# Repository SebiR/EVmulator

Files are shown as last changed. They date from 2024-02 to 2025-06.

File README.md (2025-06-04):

> [!CAUTION]
> This project includes dangerous voltages of 230V/400V, a bit of tinkering and (public) charging infrastructure.
> Build and use this project only if you know what you are doing. I am not liable for injuries or damages!

# EVmulator
A small PCB to go into IEC 62196 Typ 2 EV charging plugs to emulate a car to use a charging station as a normal outlet.

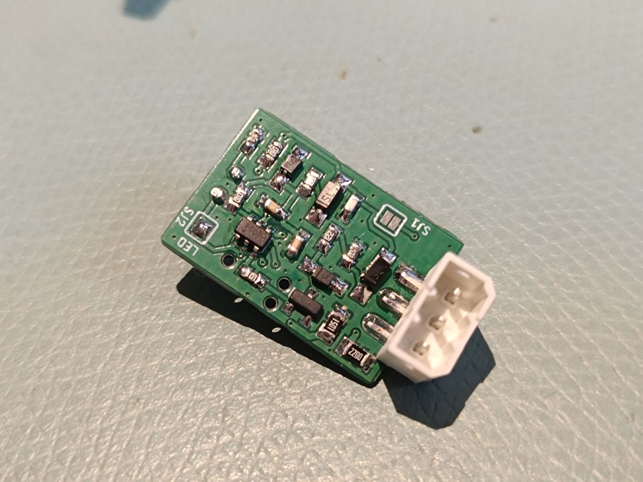
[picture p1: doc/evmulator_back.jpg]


It's currently running with an ATTiny85, although an ATTiny25 will suffice. In the future it might be done with an ATTiny10.

## Features
* Two LEDs as status indicator
* Automatic switch from connected to charging
* 13 or 32A selectable current
* EVSE Pilot monitoring
* Completely powered by the pilot signal

## Function

The EVmulator simulates a connected car for the EVSE (electric vehicle supply equipment, the wallbox)

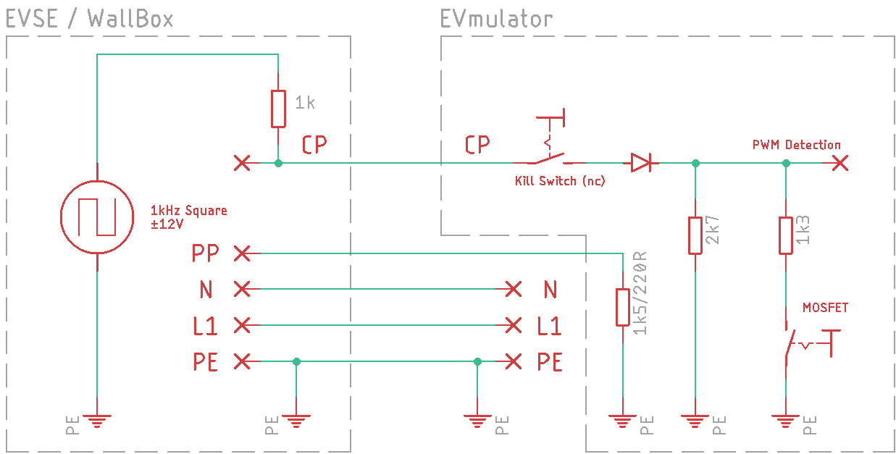
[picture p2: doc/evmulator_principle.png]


The EVSE outputs a 1kHz square wave signal with ±12V referenced to PE with 1000 ohms impedance on the CP (Control Pilot) pin and measures the voltage of the CP line.
As the EVmulator has a 1300 ohms resitor to PE, the positive voltage of the CP line is pulled to 9V and the EVSE detects a connected car.

After connecting, the EVmulator will detect the 1kHz PWM signal on the CP line and after approx. 5 seconds of PWM, the second restitor with 4.7kohms will be connected in parallel to the first resitor. As the voltage on the CP line drops to 6V, the EVSE will recognize the emulator as a charging car.

More information on Type 2 Signaling can be found here (in German):
https://www.goingelectric.de/wiki/Typ2-Signalisierung-und-Steckercodierung/

To end the charging process, a magnet is placed on the plug, opening a reed switch and signaling the end of charge to the charger.

## Usage

### Connection
Connect the three terminals of the EVmulator with the according pins of your IEC 62196 Type 2 male plug:

| Pin  | Function | Description |
|---|---|---|
| PP  | Control Pilot | maximum current of the cable defined by a resistor |
| PE  | Earth | Commond ground for communication |
| CP  | Control Pilot | Communication line between car and charger |

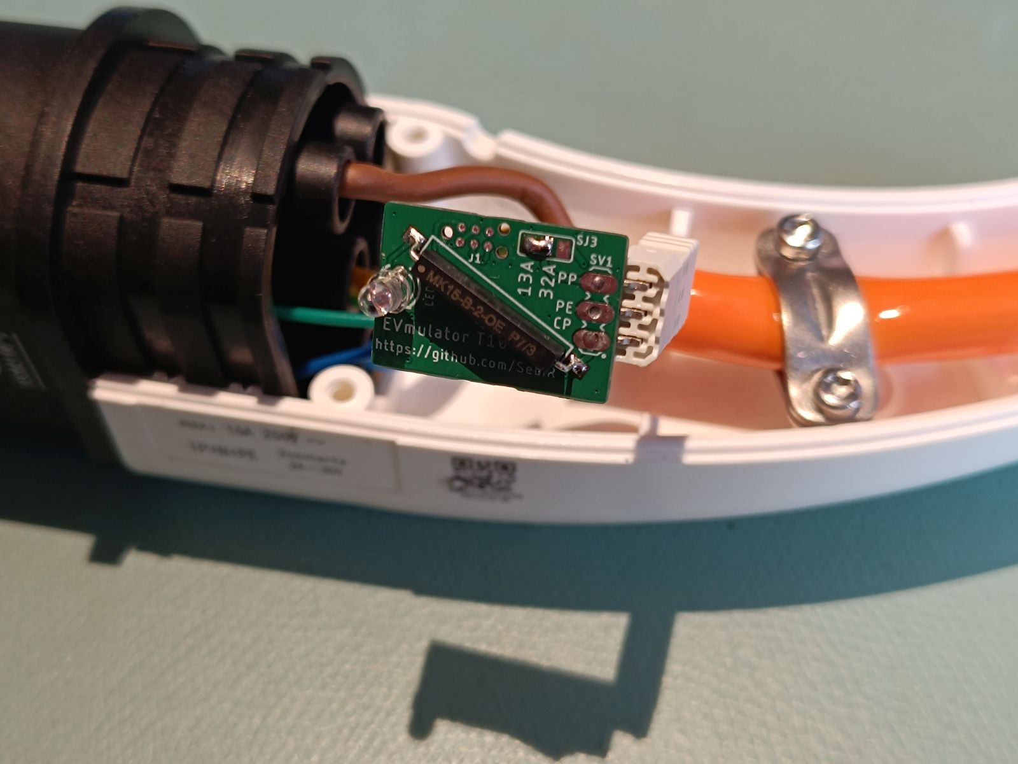
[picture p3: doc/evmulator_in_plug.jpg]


### Solder Jumpers

There are two SMT solder jumpers located on the component side of the PCB:<br>
**SJ1** bypasses the internal reed switch in case you want to use a key switch or a push button to stop the charging process. Use NC (normally closed "openener" switches).<br>
**SJ2 LED** has to be closed after flashing the microcontroller to activate the status LED. The TPI programming interface is a bit finicky when it comes to other components on the programming lines.<br>

And there's one solder jumper on the side with the reed switch:<br>
**SJ3 13/32A** let's you select between a max. current of 13A or 32A depending on your application. Always make sure to use rated cables and connectors!

### Inside the plug

Drill a 3mm hole in the plug and put the LED through it. Fix the board with a bit of silicone or hot glue and you're done!

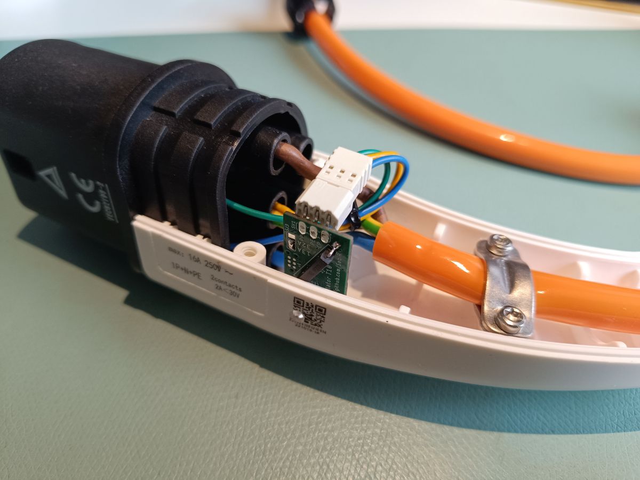
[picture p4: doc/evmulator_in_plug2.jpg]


If you want, you can add a label:

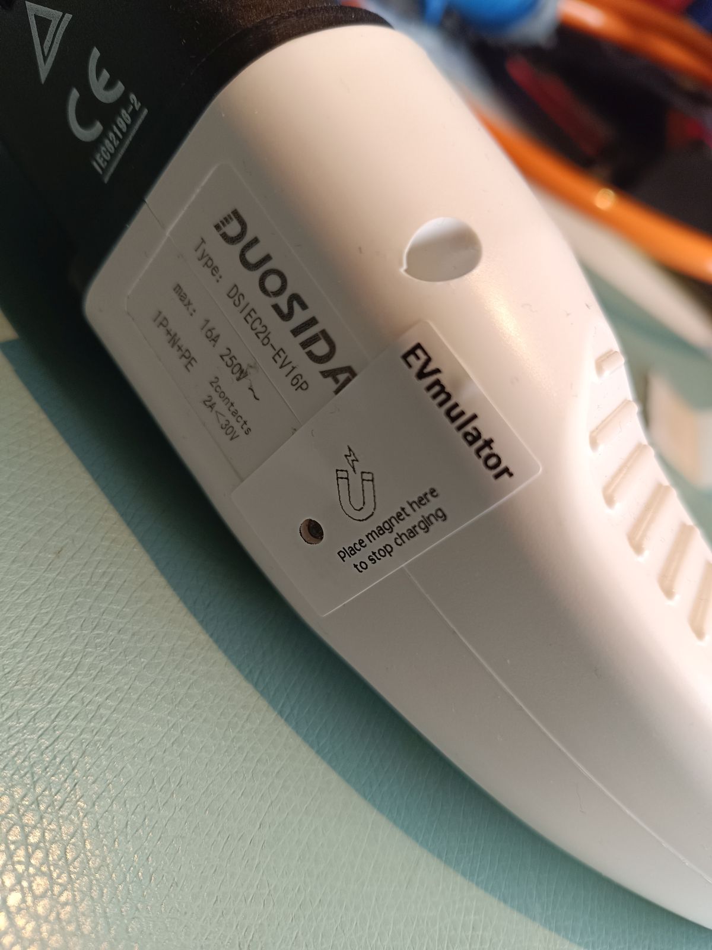
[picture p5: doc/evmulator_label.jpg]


### In the field
Just connect you Type 2 plug to the wallbox or charging station and authorize the charging process as you would normally.
The EVmulator will signal the charger that a car has been connected and that it is charging.<br>

To stop the charging process, place a magnet over the reed switch and unplug the plug.

| LED Behavior | State |
|---|---|
| Quick blink (1 ms flash every ~32 ms) | Idling, waiting for CP signal |
| Slow blink (1 ms flash every ~125 ms) | Checking if the CP signal is valid |
| Very slow blink (1 ms flash every ~1 s) | Charging |

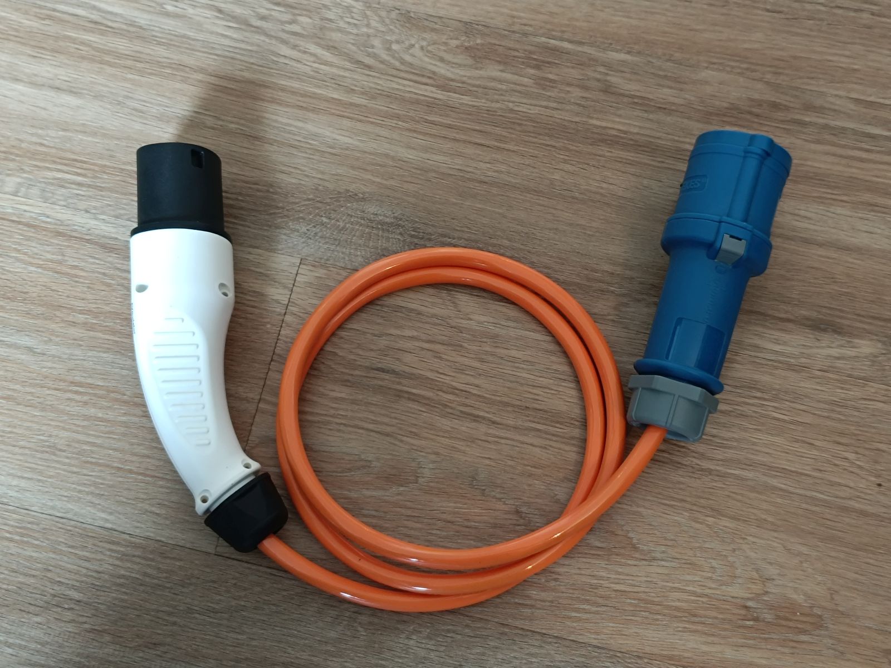
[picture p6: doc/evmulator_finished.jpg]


## Firmware

The firmware is written for the ATTiny10 microcontroller using the Arduino IDE and the <a href="https://github.com/technoblogy/attiny10core">attiny10core</a> board definitions.

### Hardware Configuration

| Pin  | Function | Description |
|---|---|---|
| PB0  | LED Output | Blinks to indicate system state |
| PB1  | CHARGE_ON (Output) | Controls a MOSFET for to signal Charging state |
| PB2  | Frequency Input | Connected to external ~1kHz square wave, also Timer0 clock source |

### System Clock and Power Settings

- The system clock is derived from the 128 kHz Watchdog oscillator.
- A clock prescaler divides this to 32 kHz system frequency.
- The ADC and analog comparator are disabled to save power.
- The microcontroller primarily stays in `SLEEP_MODE_IDLE`, waking periodically via the Watchdog Timer interrupt.

### State Machine

The firmware operates in three states:

1. **IDLE**  
   - Wakes every ~32 ms via WDT.
   - If no external clock signal is detected (TCNT0 == 0), stays in IDLE.
   - If a clock signal is consistently present for 10 cycles, transitions to MEASURE.

2. **MEASURE**  
   - Wakes every ~125 ms.
   - Measures frequency using Timer0 (externally clocked).
   - If the frequency is above 500 Hz for 10 cycles, transitions to CHARGE.
   - Remains in MEASURE as long as signal is present and below 500 Hz.

3. **CHARGE**  
   - Wakes approximately every second.
   - Enables the CHARGE_ON MOSFET (PB1 high).
   - If frequency drops below 500 Hz for 5 consecutive cycles, reverts to MEASURE.

### LED Signal Behavior

The LED (on PB0) provides visual feedback for debugging and operational awareness:

| LED Behavior | State(s) | Meaning |
|---|---|---|
| Quick blink (1 ms flash every ~32 ms) | IDLE | Signal inactive or low frequency detected |
| Slow blink (1 ms flash every ~125 ms) | MEASURE | Signal detected, measuring frequency |
| Very slow blink (1 ms flash every ~1 s) | CHARGE | Charging enabled, monitoring signal |

All blinking is implemented by flashing the LED for 1 ms during each WDT interrupt.

### Power Optimization

- All unnecessary peripherals (ADC, comparator) are disabled.
- WDT interval is adjusted dynamically based on state.
- Sleep modes and minimal active time are used to reduce power consumption.
- Timer0 uses an asynchronous external clock, allowing operation even in low-power modes.

## Other

During development, I also created the <a href="https://github.com/SebiR/EVSE_Emulator_Shield">EVSE Emulator Shield</a> to test the EVmulator

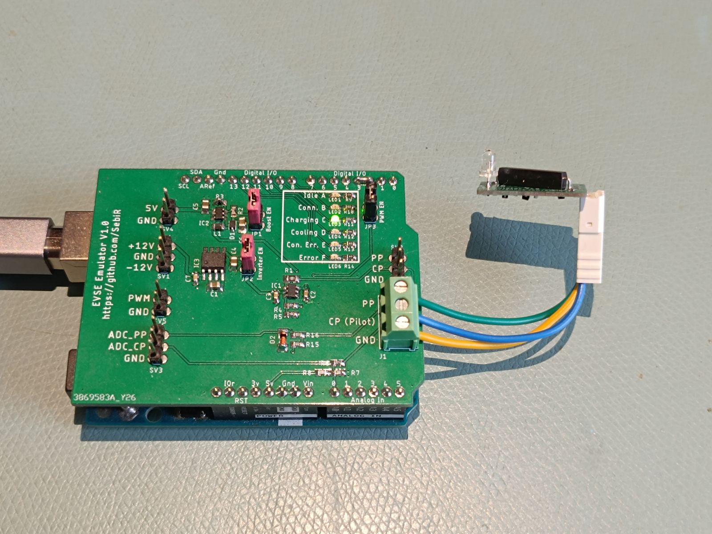
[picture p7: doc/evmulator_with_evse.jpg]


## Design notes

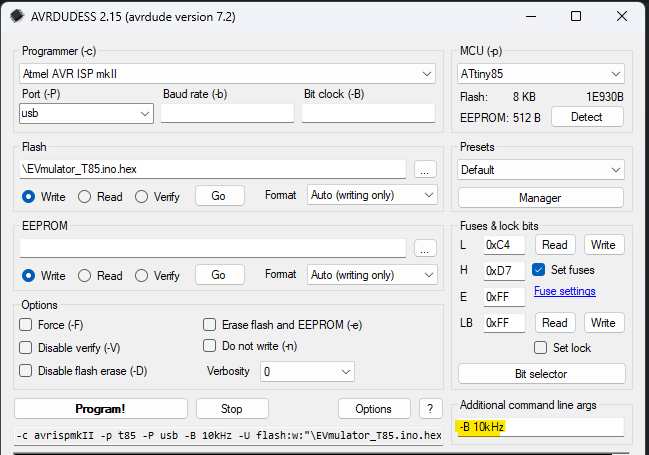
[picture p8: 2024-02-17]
doc/avr_dudess_settings.png

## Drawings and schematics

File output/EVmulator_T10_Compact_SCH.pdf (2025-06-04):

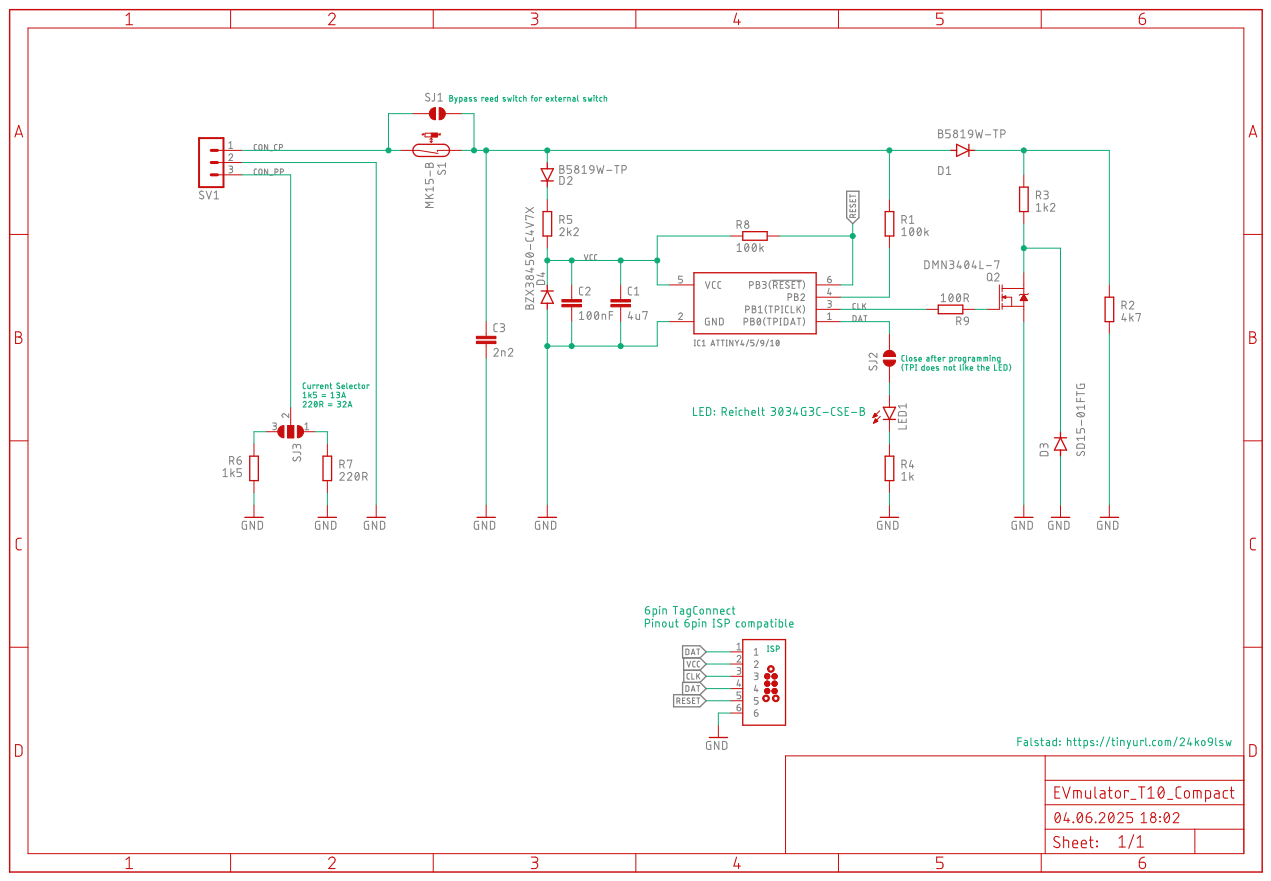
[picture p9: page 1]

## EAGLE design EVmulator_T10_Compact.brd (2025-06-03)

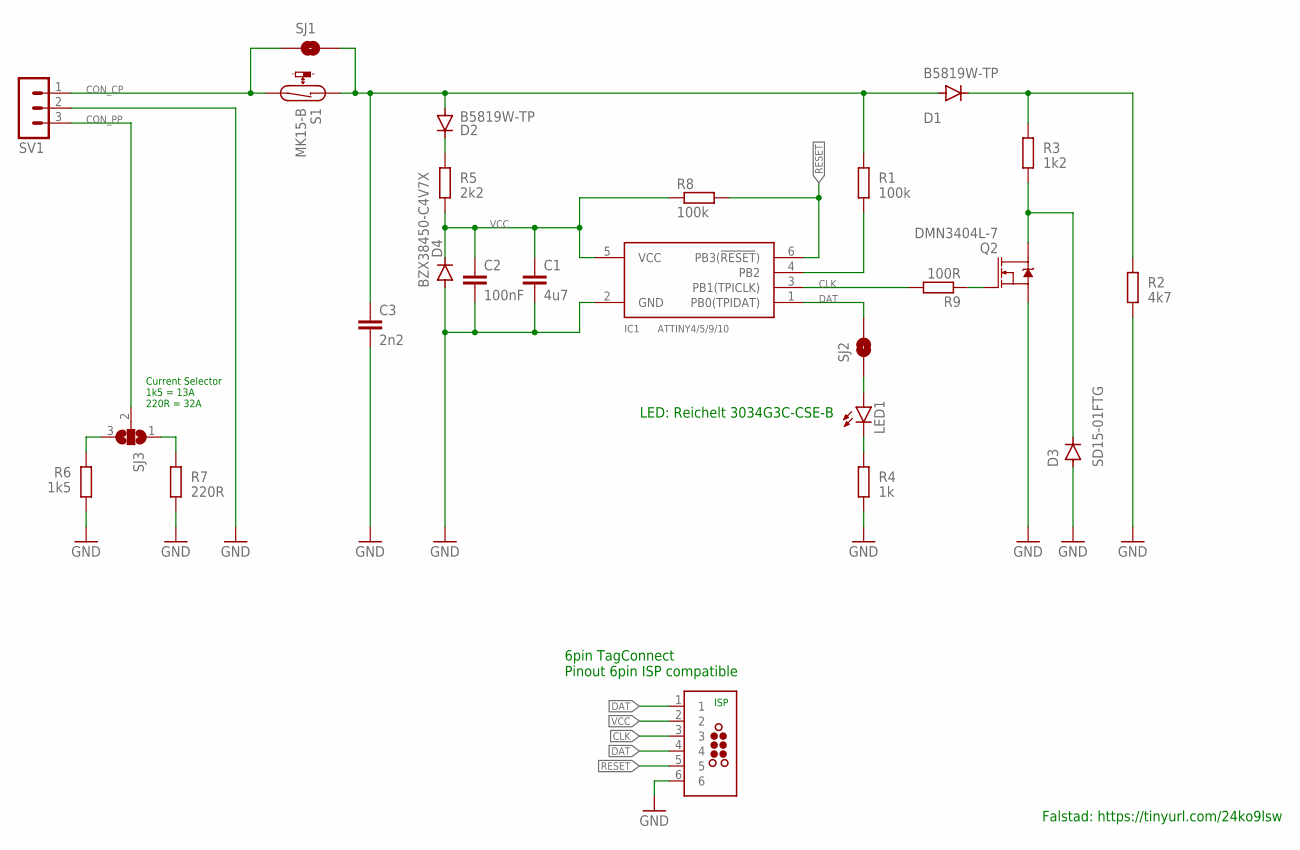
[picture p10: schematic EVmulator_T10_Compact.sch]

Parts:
C1: 4u7; C0603
C2: 100nF; C0603
C3: 2n2; C0603
D1, D2: B5819W-TP; SOD123
D3: SD15-01FTG; SOD323-W
D4: BZX38450-C4V7X; SOD323-W
IC1: ATTINY4/5/9/10; SOT23-6
J1: TAG-CONNECT_TC2030-MCP-NL
LED1: LED3MM
Q2: DMN3404L-7; SOT23-3
R1, R8: 100k; R0603
R2: 4k7; R0603
R3: 1k2; R0603
R4: 1k; R0603
R5: 2k2; R0603
R6: 1k5; R0805
R7: 220R; R0805
R9: 100R; R0603
S1: MK15-B; MK15
SJ1, SJ2: JUMPER-SMT_2_NO_SILK; SMT-JUMPER_2_NO_SILK
SJ3: SJ2W; SJ_2
SV1: MA03-1

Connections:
CLK: IC1.3 (PB1(TPICLK)), J1.3, R9.2
CON_CP: S1.2, SJ1.1, SV1.1
CON_PP: SJ3.2, SV1.3
CP: C3.1, D1.A, D2.A, R1.1, S1.1, SJ1.2
DAT: IC1.1 (PB0(TPIDAT)), J1.1, J1.4, SJ2.2
GND: C1.2, C2.2, C3.2, D3.A, D4.A, IC1.2 (GND), J1.6, Q2.2 (S), R2.1, R4.1, R6.1, R7.1, SV1.2
unnamed: Q2.1 (G), R9.1
unnamed: IC1.4 (PB2), R1.2
unnamed: D3.C, Q2.3 (D), R3.1
unnamed: LED1.K (C), R4.2
unnamed: D1.C, R2.2, R3.2
unnamed: D2.C, R5.2
unnamed: LED1.A, SJ2.1
unnamed: R6.2, SJ3.3
unnamed: R7.2, SJ3.1
RESET: IC1.6 (PB3(!RESET!)), J1.5, R8.2
VCC: C1.1, C2.1, D4.C, IC1.5 (VCC), J1.2, R5.1, R8.1

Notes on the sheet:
Falstad: https://tinyurl.com/24ko9lsw
Current Selector 1k5 = 13A 220R = 32A
ISP
6pin TagConnect Pinout 6pin ISP compatible
LED: Reichelt 3034G3C-CSE-B

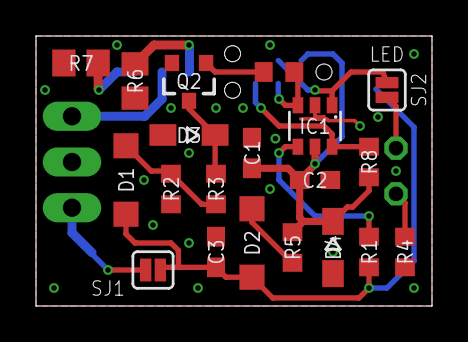
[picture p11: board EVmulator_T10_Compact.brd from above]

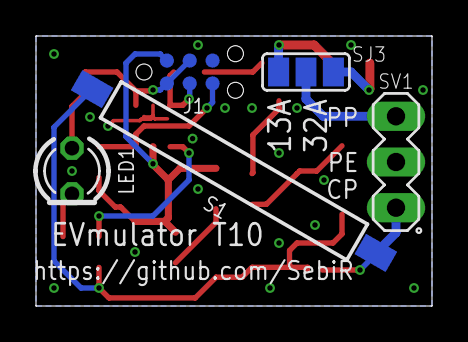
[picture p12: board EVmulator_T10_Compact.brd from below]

Board: 2 copper layers, 22.0 x 15.0 mm, 25 parts (5 on the bottom side), 17 nets.

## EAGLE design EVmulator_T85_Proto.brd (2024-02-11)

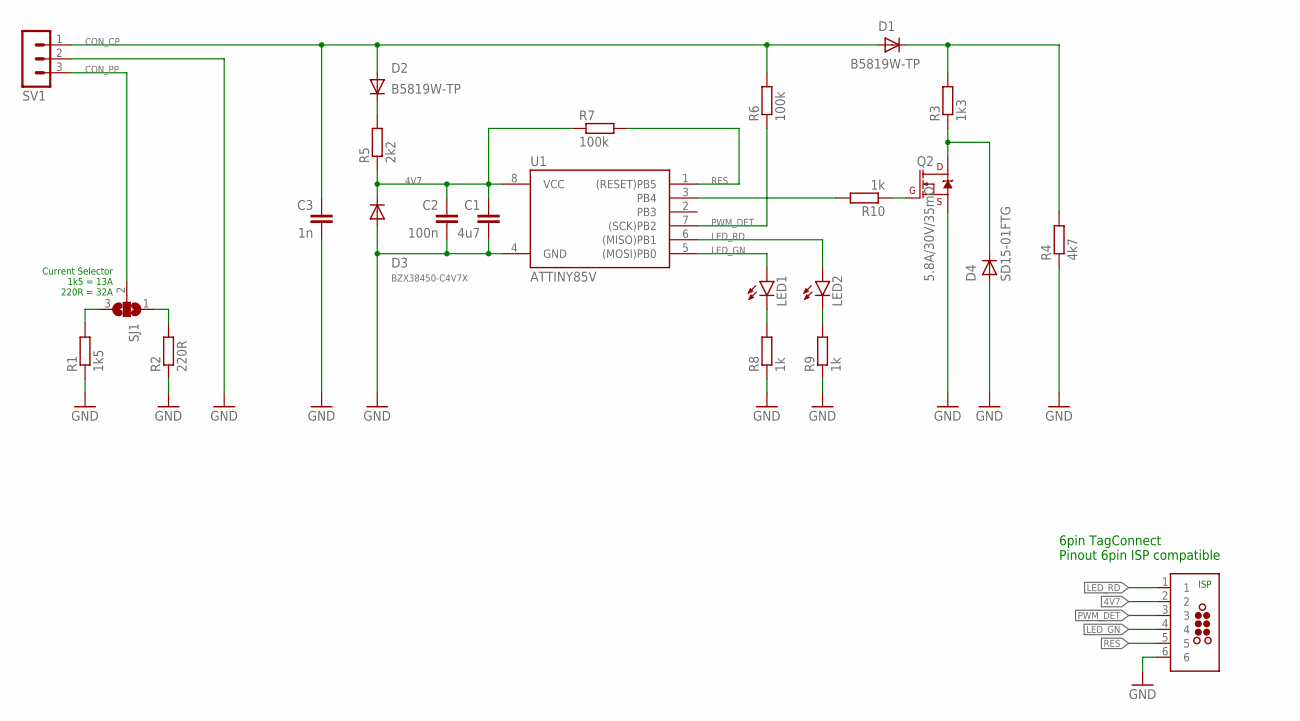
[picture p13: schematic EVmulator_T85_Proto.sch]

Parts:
C1: 4u7; C0603
C2: 100n; C0603
C3: 1n; C0603
D1, D2: B5819W-TP; SOD-123
D3: BZX38450-C4V7X; SOD-323F
D4: SD15-01FTG; SOD-323F
J1: TAG-CONNECT_TC2030-MCP-NL
LED1, LED2: LEDCHIP-LED0603; CHIP-LED0603
Q2: 5.8A/30V/35mΩ; SOT23-3
R1: 1k5; R0805
R2: 220R; R0805
R3: 1k3; R0603
R4: 4k7; R0603
R5: 2k2; R0603
R6, R7: 100k; R0603
R8, R9, R10: 1k; R0603
SJ1: SJ2W; SJ_2
SV1: MA03-1
U1: ATTINY85V; SOIC8_200

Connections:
4V7: C1.1, C2.1, D3.C, J1.2, R5.1, R7.1, U1.8 (VCC)
CON_CP: C3.1, D1.A, D2.A, R6.2, SV1.1
CON_PP: SJ1.2, SV1.3
GND: C1.2, C2.2, C3.2, D3.A, D4.A, J1.6, Q2.2 (S), R1.1, R2.1, R4.1, R8.1, R9.1, SV1.2, U1.4 (GND)
LED_GN: J1.4, LED1.A, U1.5 ((MOSI)PB0)
LED_RD: J1.1, LED2.A, U1.6 ((MISO)PB1)
unnamed: R1.2, SJ1.3
unnamed: R2.2, SJ1.1
unnamed: LED1.C, R8.2
unnamed: LED2.C, R9.2
unnamed: D4.C, Q2.3 (D), R3.1
unnamed: D1.C, R3.2, R4.2
unnamed: D2.C, R5.2
unnamed: Q2.1 (G), R10.1
unnamed: R10.2, U1.3 (PB4)
PWM_DET: J1.3, R6.1, U1.7 ((SCK)PB2)
RES: J1.5, R7.2, U1.1 ((RESET)PB5)

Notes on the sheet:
Current Selector 1k5 = 13A 220R = 32A
ISP
6pin TagConnect Pinout 6pin ISP compatible

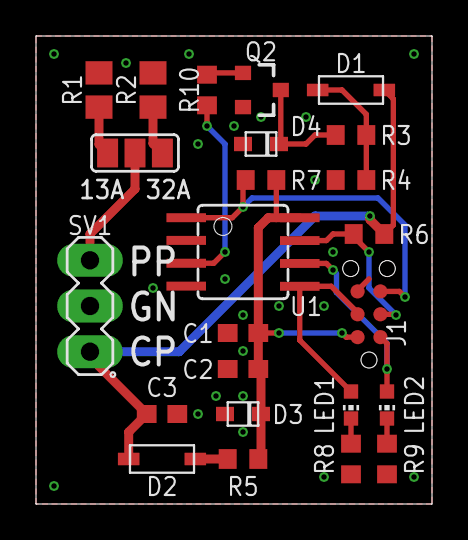
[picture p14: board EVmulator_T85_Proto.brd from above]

Board: 2 copper layers, 22.0 x 26.0 mm, 24 parts (0 on the bottom side), 17 nets.

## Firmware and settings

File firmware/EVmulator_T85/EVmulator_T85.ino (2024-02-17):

/*

Fuses:
L 0xC4
H 0xD7
E 0xFF
WD. Osc. 128 kHz
*/

#include <avr/sleep.h>
#include <avr/power.h>
#include <avr/wdt.h>
#include <avr/io.h>
#include <util/delay.h>

#define LED_GN 0  // PB0 - Green indicator LED
#define LED_RD 1  // PB1 - Red indicator LED
#define CHARGE 4  // PB4 - MOSFET to activate second resistor

#define LED_ON_TIME 5 // in ms

int pwm_good_cntr = 0;
int pwm_bad_cntr = 0;
uint8_t pwm_status = 0;

// Blank WDT interrupt
ISR(WDT_vect) {
}

// Enter Sleep Mode
void enterSleep(void) {
  //  Unfortunately, power down stops the timers, so we can't use it
  //set_sleep_mode(SLEEP_MODE_PWR_DOWN);
  set_sleep_mode(SLEEP_MODE_IDLE);
  sleep_enable();
  sleep_mode();  // Start sleep mode

  // Nothing happens until WDT timeout

  sleep_disable();
  power_all_enable();
}

// Setup the Watch Dog Timer (WDT)
// http://modelleisenbahn-steuern.de/controller/atmega8/6-5-wdtcr-register-atmega8.htm
// https://www.best-microcontroller-projects.com/attiny-ultra-low-power.html
void setupWDT() {

  MCUSR &= ~(1 << WDRF);  // Clear the WDRF (Reset Flag).

  // Setting WDCE allows updates for 4 clock cycles end is needed to
  // change WDE or the watchdog pre-scalers.
  WDTCR |= (1 << WDCE) | (1 << WDE);

  // WD triggers every ~74ms
  WDTCR = (0 << WDP3) | (0 << WDP2) | (1 << WDP1) | (0 << WDP0);

  WDTCR |= _BV(WDIE);  // Enable the WDT interrupt.
}

//  Timer 0 is used as a counter to check the presence of the pilot PWM signal
void setupT0() {

  // Normal port operation, OC0A/OC0B disconnected, Normal Timer operation
  TCCR0A = (0 << COM0A1) | (0 << COM0A0) | (0 << COM0B1) | (0 << COM0B0) | (0 << WGM01) | (0 << WGM02);

  // Ext. T0 as input. Rising edge
  TCCR0B = 0;
  TCCR0B = (0 << FOC0A) | (0 << FOC0B) | (0 << WGM02) | (1 << CS02) | (1 << CS01) | (1 << CS00);
}


void setup() {

  pinMode(LED_GN, OUTPUT);
  pinMode(LED_RD, OUTPUT);
  pinMode(CHARGE, OUTPUT);

  // Unused pins as pulled up inputs
  pinMode(2, INPUT_PULLUP);
  pinMode(3, INPUT_PULLUP);

  digitalWrite(CHARGE, LOW);
  digitalWrite(LED_GN, LOW);
  digitalWrite(LED_RD, LOW);

  ADCSRA &= ~(1 << ADEN);  // Disable ADC

  setupT0();
  setupWDT();
}

void loop() {

  // Each 74ms -> 1kHz means 74 counts
  // 30 = 900Hz, 40 =1.2kHz
  if ((TCNT0 >= 60) && (TCNT0 <= 90)) {
    pwm_bad_cntr = 0;
    pwm_good_cntr++;
  } else {
    pwm_good_cntr = 0;
    pwm_bad_cntr++;
  }
  TCNT0 = 0;

  //  approx 5 seconds of good pwm and low flag
  //  74ms period time means ~15Hz
  if (pwm_good_cntr > 5 * 15 && pwm_status == 0) {
    pwm_status = 1;
    pwm_good_cntr = 0;
  } else if (pwm_bad_cntr > 5 * 15 && pwm_status == 1) {
    pwm_status = 0;
    pwm_bad_cntr = 0;
  }

  //  Pilot PWM signal is good, switch on charging indication resistor
  if (pwm_status == 1) {
    digitalWrite(LED_GN, HIGH);
    _delay_ms(LED_ON_TIME);
    digitalWrite(LED_GN, LOW);

    // Tell the EVSE we're changing from connected to charging
    digitalWrite(CHARGE, HIGH);

    // Pilot PWM signal lost, switch off charging resistor
  } else {
    digitalWrite(LED_RD, HIGH);
    _delay_ms(LED_ON_TIME);
    digitalWrite(LED_RD, LOW);

    // Signal the EVSE we're not charging but in connected mode
    digitalWrite(CHARGE, LOW);
  }

  //  Everything done, go to sleep
  enterSleep();
}

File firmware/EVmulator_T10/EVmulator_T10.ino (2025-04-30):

#include <avr/io.h>
#include <avr/interrupt.h>
#include <avr/sleep.h>
#include <avr/wdt.h>
#include <stdbool.h>

// Pin Definitions
#define LED_PIN PB0
#define CHARGE_PIN PB1

// Threshold frequency to detect good PWM
#define FREQ_THRESHOLD_HZ 500

// Watchdog Prescaler
#define WDT_32MS (1 << WDP0)
#define WDT_125MS ((1 << WDP1) | (1 << WDP0))
#define WDT_1S ((1 << WDP2) | (1 << WDP1))

// System states
typedef enum {
  IDLE,
  MEASURE,
  CHARGE
} SystemState;

volatile SystemState state = IDLE;

// Counters to switch between states
volatile uint8_t nonzero_count = 0;
volatile uint8_t highfreq_count = 0;
volatile uint8_t lowfreq_count = 0;

// Current WDT interval in ms
volatile uint16_t wdt_period_ms = 32;

void init_io(void) {
  DDRB |= (1 << LED_PIN) | (1 << CHARGE_PIN);      // LED and CHARGE as output
  PORTB &= ~((1 << LED_PIN) | (1 << CHARGE_PIN));  // Initially off
}

void init_clock(void) {
  //CCP = 0xD8;
  //CLKPSR = 0x02;  // 128kHz / 4 → 32kHz system clock
  //CCP = 0xD8;                              // Unprotect CLKMSR reg
  //CLKMSR = (0 << CLKMS1) | (1 << CLKMS0);  // Set Clock source to 128kHz WDT oscillator

  CCP = 0xD8;                                                              // Unprotect CLKPSR reg
  CLKPSR = (0 << CLKPS3) | (0 << CLKPS2) | (1 << CLKPS1) | (0 << CLKPS0);  // Divide Clock by 4 -> 32kHz
}

void disable_unused_modules(void) {
  //DIDR0 = 0xFF;           // DO NOT USE
  ACSR |= (1 << ACD);      // analog comparator off
  ADCSRA &= ~(1 << ADEN);  // ADC off
  PRR = (1 << PRADC);      // Power down ADC
}

void init_timer(void) {
  TCCR0A = 0x00;
  TCCR0B = (0 << ICNC0) | (0 << ICES0) | (0 << WGM03) | (1 << WGM02) | (1 << CS02) | (1 << CS01) | (1 << CS00);
  TCNT0 = 0;
}

// Calculation: 500 Hz * Interval(ms) / 1000 = threshold
uint16_t get_frequency_threshold(void) {
  return (FREQ_THRESHOLD_HZ * wdt_period_ms) / 1000;
}

void set_watchdog(uint8_t wdt_prescaler) {
  cli();
  wdt_reset();

  // Update WDT interval
  if (wdt_prescaler == WDT_32MS) {
    wdt_period_ms = 32;
  } else if (wdt_prescaler == WDT_125MS) {
    wdt_period_ms = 125;
  } else if (wdt_prescaler == WDT_1S) {
    wdt_period_ms = 1000;
  }

  CCP = 0xD8;
  WDTCSR = (1 << WDIE) | wdt_prescaler;
  sei();
}

void sleep_idle(void) {
  set_sleep_mode(SLEEP_MODE_IDLE);
  //set_sleep_mode(SLEEP_MODE_STANDBY);
  sleep_enable();
  sleep_cpu();
  sleep_disable();
}

// Flash LED (~1ms)
void pulse_led(void) {
  PORTB |= (1 << LED_PIN);
  for (volatile uint8_t i = 0; i < 80; i++) {
    __asm__ __volatile__("nop");
  }
  PORTB &= ~(1 << LED_PIN);
}

// Watchdog ISR
ISR(WDT_vect) {
  uint16_t tcnt = TCNT0;
  TCNT0 = 0;
  uint16_t freq_thresh = get_frequency_threshold();

  pulse_led();

  // State FSM
  switch (state) {
    case IDLE:
      if (tcnt == 0) {
        nonzero_count = 0;
      } else {
        nonzero_count++;
        if (nonzero_count >= 10) {
          nonzero_count = 0;
          set_watchdog(WDT_125MS);
          state = MEASURE;
        }
      }
      break;

    case MEASURE:

      if (tcnt == 0) {
        nonzero_count = 0;
        set_watchdog(WDT_32MS);
        state = IDLE;
      } else if (tcnt > freq_thresh) {
        highfreq_count++;
        if (highfreq_count >= 10) {
          highfreq_count = 0;
          set_watchdog(WDT_1S);
          PORTB |= (1 << CHARGE_PIN);
          state = CHARGE;
        }
      } else {
        highfreq_count = 0;
      }
      break;

    case CHARGE:
      if (tcnt < freq_thresh) {
        lowfreq_count++;
        if (lowfreq_count > 5) {
          lowfreq_count = 0;
          PORTB &= ~(1 << CHARGE_PIN);
          set_watchdog(WDT_125MS);
          state = MEASURE;
        }
      } else {
        lowfreq_count = 0;
      }
      break;
  }
}

void setup() {
  cli();
  init_clock();
  disable_unused_modules();
  init_io();
  init_timer();
  set_watchdog(WDT_32MS);  // Start in IDLE state
  sei();
}

void loop() {
  sleep_idle();
}

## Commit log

2023-09-03 * Started new HW Version (compact) * FW is running okay for the first try
    [EVmulator_T85_Compact.brd, EVmulator_T85_Compact.sch, EVmulator_T85_Proto.brd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]
2024-02-09 Finished compact version
    [EVmulator_T85_Compact.brd, EVmulator_T85_Proto.brd, EVmulator_T85_Proto.sch]
2024-02-11 changed silkscreen for the 3pin header on both boards. Updated gerbers.
    [EVmulator_T85_Compact.brd, EVmulator_T85_Compact.sch, EVmulator_T85_Proto.brd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]
2024-02-11 increased silkscreen size on compact variant
    [EVmulator_T85_Compact.brd]
2024-02-11 Made tValue Layer of compact variant more useful. Fixed airwire in compact variant
    [EVmulator_T85_Compact.brd]
2024-02-11 * moved prototype board to deprecated (will not be maintained in the future= * added connection drawing to schematic, updated output
    [EVmulator_T85_Compact.sch, EVmulator_T85_Proto.brd, EVmulator_T85_Proto.sch]
2024-02-11 added overview schematic
2024-02-16 Re-organized firmware, removed some debugging left-overs
    [EVmulator_T85_Compact.brd, EVmulator_T85_Compact.sch]
2024-02-17 * minor tweaks in the FW * Started firmware flashing instructions
    [type_2_signaling.sch]
2025-04-29 *Added Tiny10 variant
    [EVmulator_T10_Compact.brd, EVmulator_T10_Compact.sch, EVmulator_T85_Reed.brd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]
2025-04-30 * Modified Hardware
    [EVmulator_T10_Compact.brd, EVmulator_T10_Compact.sch, EVmulator_T85_Compact.brd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]
2025-06-03 Updated readme and schematics
    [EVmulator_T10_Compact.brd, EVmulator_T10_Compact.sch]
2025-06-03 * Moved T85 FW do deprecated and added recent hex file
    [EVmulator_T85_Compact.brd, EVmulator_T85_Compact.sch]
2025-06-04 * added label * updated documentation
    [type_2_signaling.sch]
2025-06-04 Annotated schematic a bit more, created new PDF of schematics
    [EVmulator_T10_Compact.sch]

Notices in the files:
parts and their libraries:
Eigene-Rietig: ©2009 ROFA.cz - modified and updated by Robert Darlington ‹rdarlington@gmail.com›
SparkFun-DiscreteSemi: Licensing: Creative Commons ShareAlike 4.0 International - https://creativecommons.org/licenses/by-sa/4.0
